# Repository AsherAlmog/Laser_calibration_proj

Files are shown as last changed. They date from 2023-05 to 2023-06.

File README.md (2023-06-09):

# Laser calibration
This repo contains code scripts to collect data of a laser beam's location using stepper motors that move the laser.<br>
The steppers are assumed to be controlled by an Arduino controller.<br>
We included some 3D models that we used to connect stepper motors to optical stages.<br>
This repo also contains a script for training a deep learning model to estimate the coordinates of the beam.<br>
# 3D models
For the ones who wish to build a similar setup by connecting 5mm stepper motors to ThorLabs' manual stages,
we included some useful 3D models under the folder *3D_models_STL_files*:<br>
The first is a coupler that connects the motor's shaft to the manual stage, named *coupler_13mm.stl*
and the second is *stepper_holder_z.stl* that is a stand for the motor.
# data collection process:
- **Arduino** - serial_comm_arduino.ino:<br>
This script is used to recieve a json file with a position to move to,
deserialize it and move 3 stepper motors accordingly.
- **Raspberry py** - data_collection.py:<br>
this script communicates with the arduino. it sends it a position to move to decoded in a json file,
and waits for an ack message. Then it captures a picture using the picamera and saves it in a directory
that is *hard coded* in the code. The next step is telling the arduino to nove back to the initial position.
there is a range of positions to iterate through that are also hard coded and should be changed manually if necessary.<br>
The following schematic shows the process:<br>
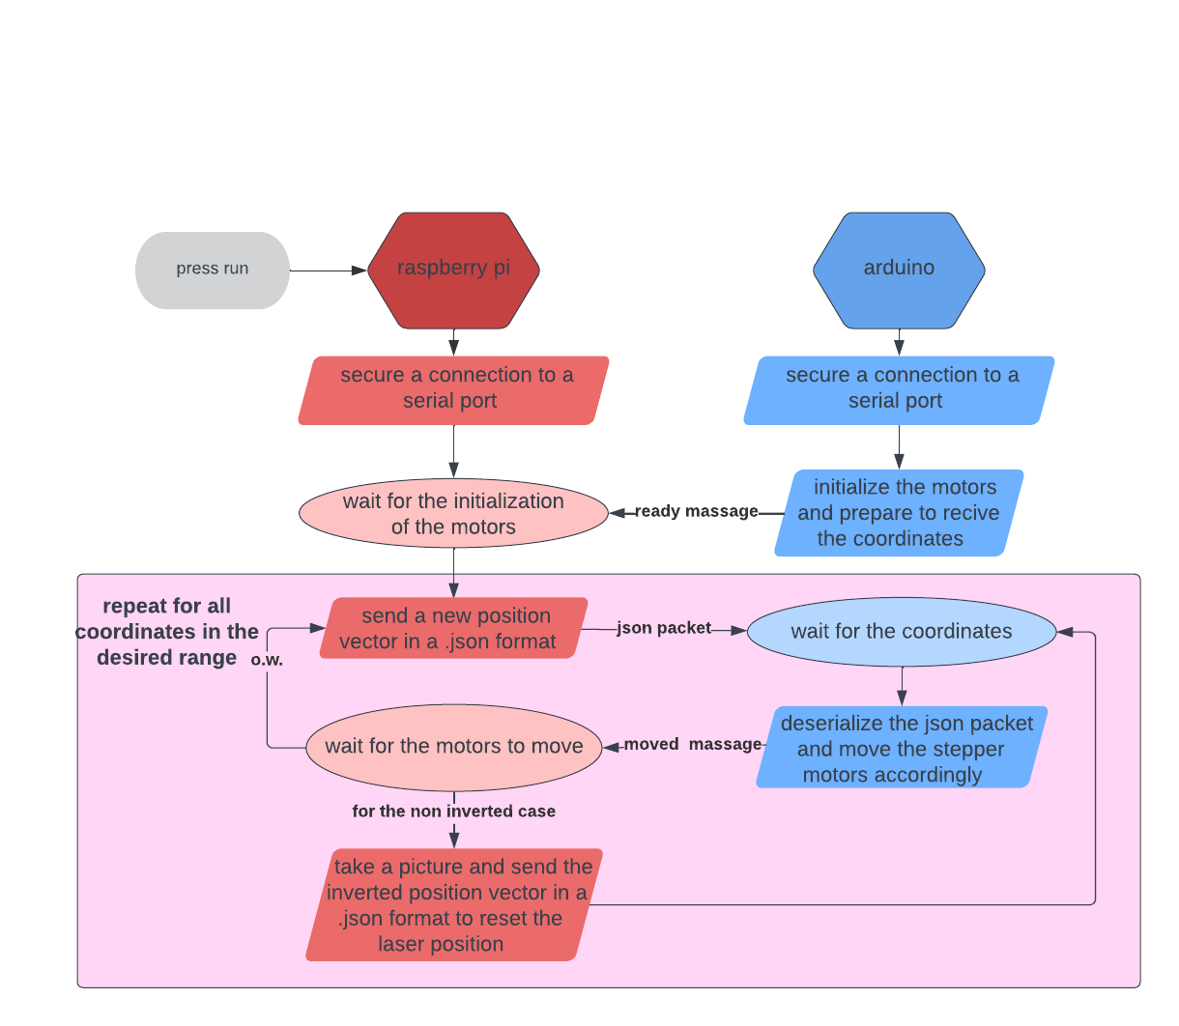
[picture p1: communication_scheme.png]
communication Image
 <br>
**In order to collect new data, follow the following steps:** <br>
1. Upload the *data_collection.ino* script to your Arduino <br>
2. In *data_collection.py*, change *root_dir* to the local directory in which you want to save the images. <br>
3. Still in *data_collection.py*, change the fields *bottom_bound*, *upper_bound* and *range_arr*. They're all organized in this order: [x,z,theta].
bottom_bound should be the lowest number of motor spins for each coordinate, upper_bound is the highest and range_arr determines the 
difference between each consecutive locations.<br>
4. Modify *num_iterations* to the number of images you wish to take for each coordinate.<br>
5. Run *data_collection.py* on your Raspberry-pi with the correct [camera module with the Sony IMX477 sensor](https://www.adafruit.com/product/4561).  <br>
# Deep learning model
original images: (1280, 960,3) images<br>
data transforms: turning the images to tensors<br>
The selected model: a pre-trained resNet-18 , with a modified FC layer<br>
Loss function : MSE<br>
optimizer: Adam<br>
Learning rate: starts at 0.01 and decreases by 70% every 8 epochs <br>
**In order to train a model:** <br>
Please change the *data_dir* variable in *train/main.py* to be the local directory that you saved the images in. <br>
Now run the script and you'll have a file named *model_params.pth* that contains the trained model's parameters.<br>
# Results
The MSE loss decreases significantly (starts at ~3, ends at ~0.05). <br>
Test loss is as below: <br>
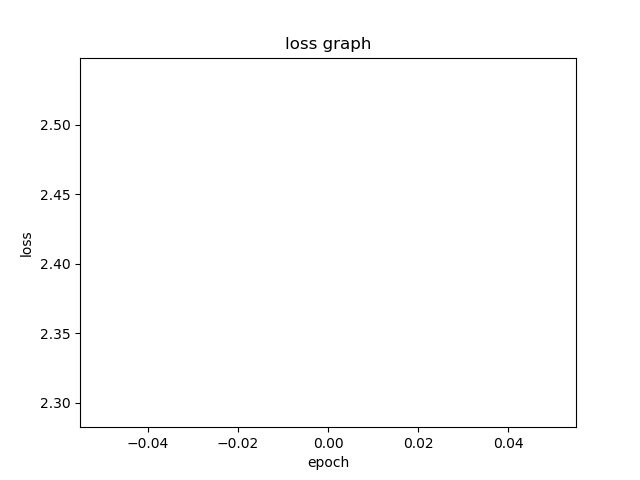
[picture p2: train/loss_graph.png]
test loss Image


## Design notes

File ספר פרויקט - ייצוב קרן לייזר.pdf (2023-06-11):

בי"ס להנדסת חשמל

## פרויקט מס' 22-1-1-2456

# ספר פרויקט

## שם הפרויקט: פרויקט ייצוב קרן לייזר

## מבצעים:

## שם: אלמוג אשר, ת"ז: 322417916

## שם: בר זהבי, ת"ז: 323014894

## מנחה: חן כהן

### מנחה נוסף: עופר כפיר

## מיקום ביצוע הפרויקט: מעבדת לייזרים בבניין

ברודקום )המעבדה של עופר כפיר(

## תקציר עבודה

כדי לייצב קרן לייזר נדרש לדעת את המיקום שלה בנקודת ייחוס, וכן את הזווית בה היא מתקדמת. אלו הן 4 דרגות חופש, שתיים בציר האופקי ושתיים באנכי.

השיטה כיום לאפיין את פרמטרים אלו של קרן לייזר, וכך גם לייצב אותה ע"י מראה ממונעת, היא שימוש בעדשות ומצלמות: מצלמה אחת מצלמת את הקרן כדי לקבוע את מיקומה. המצלמה הנוספת מקליטה את הפוקוס של הקרן לאחר עדשה, אשר נושא מידע על הזווית.

בפרוייקט זה ניתן היה להשתמש בתווך מפזר, דוגמת נייר לבן, חלון שירותים, ספוג או קיר, במקום עדשות. מכיוון שהפיזור יהיה תלוי במיקום הקרן וכן בזוויתה, שילובו עם מצלמה בודדת יאפשר את אפיון שני הפרמטרים האלו של הקרן על מצלמה יחידה, לאחר כיול או אימון המערכת.

הפיזור המתקבל מהקרן נקלט ע"י מצלמה של MP12 עם סנסור מסוג 477Imx Sony שמחוברת לבקר .Raspberry-pi

הבסיס התיאורטי לפרויקט הוא שיטה שעדיין לא מיצו את כל הפוטנציאל שלה והיא שימוש בתמונות הפיזורים של לייזר (images-speckle (על מנת ללמוד מאפיינים הן על הקרן והן על התווך המפזר.

- למשל בניטור תהליך התכה של מתכות בהם

i
השימוש בתמונות פיזורים כיום נעשה בעיקר בתהליכי ניטור רוצים לאפיין תכונות גיאומטריות של המתכת והרכב המתכת. או למשל בתהליכים ביו טכנולוגיים בהם יש לנטר את הביו- מסה של האורגניזם.

אנחנו מנסים לנצל את המידע הטמון בפיזורים למטרות אחרות – שיערוך של מיקום הקרן.

תמונות הפיזורים שמתקבלות על המצלמה שלנו משמשות כקלט לרשת למידה עמוקה מסוג 18Net-Res, שמוציאה כפלט את החיזוי של הזוויות והמיקום המרחבי שממנו נורתה הקרן. החיזוי משמש אותנו למעגל משוב, שמסתמך על פלט הרשת על מנת להחזיר את קרן הלייזר לראשית הצירים.

הן הזווית והן המיקום המרחבי נשלטים ע"י מנועי צעד שמחוברים לבקר מסוג Arduino, שמאפשרים לנו איסוף נוח של תמונות ומעגל משוב אוטומטי שמחזיר את הקרן לראשית. בפרויקט הוכחנו שאכן ניתן לכייל את הקרן באמצעות תמונו ת הפיזורים, לאחר שאימון על מאות קואורדינטות שונות עם אלפי דוגמאות קלט הביא את המודל לשגיאה ריבועית ממוצעת שמת קרבת לאפס הן עבור קבוצת האימון והן עבור קבוצת טסט.

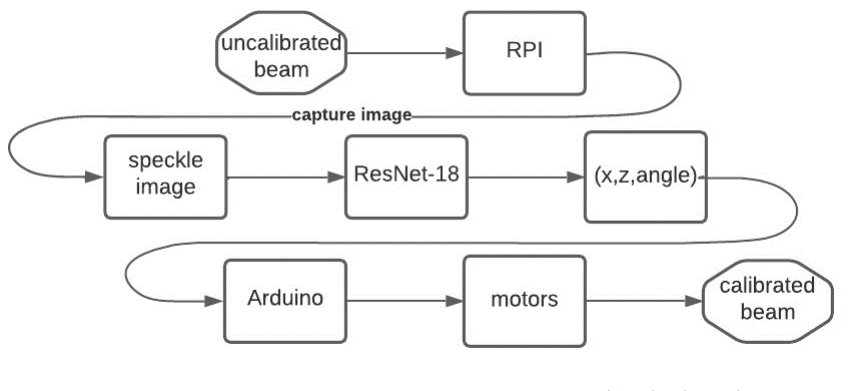
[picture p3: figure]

איור 1 - דיאגרמת בלוקים של תהליך הקליברציה

תוכן עניינים
תקציר עבודה 2 |
הקדמה 4 |
רקע תיאורטי 5 |
מימוש 6 |
המערכת הפיזית6 | :
אוטומציה והתממשקות למנועים: | 6
רכיבי המערכת הפיזית | 7
מימוש בתוכנה 13 |
תקשורת בין בקר ה-pi Raspberry לבקר ה-Arduino | 13
רשת למידה עמוקה | : 14
תוצאות 17 |
מסקנות 18 |
תיעוד 20 |
ביבליוגרפיה20 |

טבלת איורים

איור 1 - דיאגרמת בלוקים של תהליך הקליברציה | 2
איור 2 - המערכת הפיזית במהלך צילום תמונת פיזורים | 6
איור 3 - תמונה של בקר הראסברי-פאי 4 | 7
איור 4 - חיבורי המצלמה לפיני ה-GPIO של הבקר | 7
איור 5 - תמונה של בקר הארדואינו-מגה | 8
איור 6 - תמונה של ה1.4- RAMPS | 9
איור 7 - החיבורים הנחוצים בין הארדואינו ל -RAMPS וממנו למנועי הצעד | 9
איור 8 - סכמה של1.4 RAMPS | 10
איור 9 - חיבורי ה-PCB של ה-RAMPS | 10
איור 10 - הדרייבר שמניע את מנועי הצעד בקונפיגורציית חיבור בסיסית למנוע | 11
איור 11 - סכמה של מעגל Bridge-H | 12
איור 12 - קונפיגוריות של Bridge-H עבור סיבובים שמאלה וימינה | 12
איור 13 התקשורת בין הראסברי-פאי לארדואינו בעת איסוף הדאטה | 14
איור 14 - דיאגרמת בלוקים של השכבות ב-18-ResNet | 14

איור 15 - גרף השגיאה הריבועית הממוצעת בעת אימון המודל עבור קבוצת האימון וקבוצת הטסט .... 17

## הקדמה

פרויקט זה עוסק בכיול של קרן לייזר. מטרת העל של הפרויקט שלנו היא להצליח לבצע כיול של קרן לייזר אך ורק על סמך תמונות פיזורים של הקרן, שהן תמונות של הקרן שמתקבלות לאחר מעבר שלה דרך תווך מפזר שאינו שקוף. כיום תמונות פיזורים משמשות בעיקר לחיתוך וריתוך של מתכות ועוד לא מנוצלות לצרכים של שערוך מיקום, והפרויקט שלנו בא לבחון האם ניתן לנצל את המידע שטמון בתוך תמונות הפיזורים של הלייזר גם לצורך שיערוך המיקום של הקרן. את המשימה הכללית הזו ניתן לפרק למספר תתי משימות שהיה עלינו לבצע:
- ראשית, היה עלינו להקים מערכת אופטית שבבסיסה תכלול לייזר ותווך מפזר, ותאפשר שליטה גם במיקומו המרחבי של הלייזר וגם בזווית הפגיעה.
- המשימה השנייה היא להפוך את המערכת הפיזית ממערכת ידנית למערכת אוטומטית בצורה פשוטה וזולה – מאחר והמטרה בפרויקט היא גם לפשט באופן פרקטי את הכיול הן מבחינת נוחות למשתמש והן מבחינת עלויות הכיול, בנינו בתור התחלה מערכ ת שניתנת לשליטה ידנית ולכן חלקיה זולים, ולא עשינו שימוש בבמות ממונעות שמחירן יכול להגיע לעשרות אלפי שקלים. לאוטומציה של המערכת יש תפקיד חשוב בפרויקט שלנו – מערכת אוטומטית יכולה לאסוף דאטה בקלות מבלי שיהיה אפילו צורך לקחת חלק באופן פיזי באיסוף הדאטה, ומערכת אוטומטית גם יכולה לבצע את הכיול של הלייזר באופן עצמאי לאחר אימון חד פעמי של רשת קונבולוציה.
- המשימה השלישית הייתה לתכנן רשת למידה עמוקה שתתאים לבעיה שלנו הן מבחינת הגודל והן מבחינת זמן הריצה העתידי שלה.
- לבסוף, עלינו להשתמש במודל המאומן כדי ליצור מערכת שתוכל לכייל את עצמה באופן אוטומטי.

הסיבה שבגללה בחרנו להשקיע את מאמצינו בלכייל קרן לייזר היא בגלל השימושים ההולכים וגוברים בלייזרים בימינו בישומים שדורשים דיוק גבוה – עבודה עם סיליקון וחיתוך של חומרים כמו מתכות ופלסטיקים, שבהם נדרש דיוק גבוה. מכשור רפואי שדורש דיוק גבוה, כמו למשל בניתוחים בעין שמצריכים לייזר והדיק של הלייזר בהם הוא קריטי.
מחקרים ביולוגיים, כמו למשל מחקרים של ה DNA שמצריכים עבודה עם לייזר וגם הם כמובן מצריכים רזולוציות גבוהות.
כל אלו מצריכים מאיתנו להגיע לרזולוציות גבוהות מאוד בכיול לייזר והופכים את הפוטניצאל האפליקטיבי של שיטת כיול נוחה ומהירה לגדול מאוד.

בפרויקט שלנו רצינו לנצל תכונה מיוחדת של הלייזר – והיא יצירת תבניות פיזורים לאחר מעבר דרך תווך מפזר, ושכל שינוי באחת מדרגות החופש של הקרן יוצר תבנית פיזורים חדשה. השינוי הזה בתבניות הפיזורים הביא אותנו להאמין שבשילוב עם רשתות למידה עמוקה וזיהוי והתאמת התבניות לקואורדינטות המתאימות, ניתן יהיה לכייל את קרן הלייזר ברזולוציות מאוד גבוהות בהסתמך אך ורק על תמונות הפיזורים שלה. כיול באופן כזה הוא מאוד פשוט, שכן בשילוב עם אוטומציה של המערכת קל מאוד לתת למערכת לאסוף דאטה לבד ולאמן בעצמה מודל מבלי אפילו להיות צריכים להיות נוכחים פיזית, וכל זאת עם מצלמה אחת בלבד שתצלם את הקרן לאחר פגיעה בתווך המפזר. זאת לעומת השיטות הקיימות כיום שמחייבות שימוש בשתי מצלמות – אחת למיקום ואחת לזווית.

בכך אנחנו מצמצמים הן את עלות הסטאפ והן את כמות המידע שצריך לעבד )פי 2 פחות מידע כי מספר הפיקסלים קטן בחצי(. הרחבה על היתרונות התיאורטיים לעומת השיטות הקיימות תיעשה בתת הסעיף הבא.

## רקע תיאורטי

הפרויקט שלנו בראש ובראשונה מתעסק בלייזר – או ב שמו המלא,לצורך
מונוכרומטי | אור | שפולא | מכשיר | הוא ,Light Amplification by Stimulated Emission of Radiation
וקוהרנטי. מונוכרמטי משמעותו ש הלייזר פולט גלים בעלי אורך גל זהה )שאצלנו נמצאים בתחום הצבע האדום(, וקוהרנטי משמעותו שאין הפרשי פאזה בין הגלים הנפלטים.
– כלומר תמונות של הקרן כפי שהן מתקבלות | ii | בפרויקט שלנו התמקדנו בתמונות פיזורים של הלייזר
לאחר מעבר דרך תווך מפזר כגון נייר, צבע לבן או כל תווך שאינו שקוף וגורם לפיזור של הלייזר. מתקבלות תמונות של מה שנראה כמו חלקיקים של הלייזר, במה שנוצר בגלל התאבכות של גלים שהיו פעם חלק מחבילת הגלים הפוגעת של קרן הלייזר וחזרו עם פאזות שונות. תיאור פשטני של גל המתפשט
(ω−k) | במרחב בכיוון x למשל יהיה A
והפאזה שלו תהיה ω − k + ()arg , כש- היא התדירות

ו-k הוא מספר הגל שפרופורציונלי להופכי של אורך הגל. ניתן למצוא אותו ע"י =

2π
λ

הייחודיות של תמונות הפיזורים היא בכך שכל שינוי קטן במיקום וזווית הפגיעה מובילים לשינוי בתמונת הפיזורים המתקבלת. זאת מאחר וכל נקודה בתווך המפזר תיתן לנו תבנית התאבכות שונה, בטח אם התווך הוא לא אחיד.
המטרה שלנו בפרויקט היא לנצל את התכונה הזו של תמונות הפיזורים כדי להצליח לכייל קרן לייזר ברזולוציות גבוהות אך ורק ע"י תמונת הפיזורים שלה. הנחת הבסיס היא שמאחר ותבנית הפיזורים תהיה שונה לכל נקודה, איסוף של כמות גדולה של תמונות פיזורים )הכמות כמובן תלויה ברזולוציה אליה רוצים להגיע(, תוכל לאפשר שיערוך של מיקום הקרן מתוך התמונה תוך שימוש במודל למידה עמוקה, ומתוך כך גם כיול של הקרן על סמך השיערוך.
, פעם | iii | כיום השיטות לכיול הקרן אינן מסתמכות על תמונות הפיזורים שלה, אם כי על צילום הקרן עצמה
אחת ישירות כדי למדוד את מיקום , שלה ופעם אחת לאחר פיזור מעדשה וצילום הקרן עם מצלמה נוספת לאחר הפגיעה בעדשה. באמצעות מיקום הפגיעה לאחר העדשה וידיעת התכונות של העדשה המפזרת ניתן לחשב מה הייתה זווית הפגיעה. שיטה נוספת שכרגע עדיין בגדר מחקר בלבד הינה צילום הקרן במספר נקודות שונות וביצוע אינטרפולציה
iv | לשיערוך המיקום של הקרן
לשיטה שאנחנו יש יתרון משמעותי על פני השיטות האלה – אנחנו צריכים רק מצלמה אחת במקום שתיים. אנחנו מציעים סביבה זולה מאוד לצורך כיול הקרן – מצלמה אחת בלבד, שני בקרים פשוטים ומספר מנועי הצעד כמספר דרגות החופש שבהן רוצים להתחשב. מעבר לעלות, החשביבות במצלמה אחת באה לידי ביטוי גם בזמן הריצה – יש פי 2 פחות מידע לעבד ולכן ניתן להשיג זמן ריצה משמעותית יותר טוב. אנחנו גם מתבססים על שיטה פשוטה בהרבה שלמעשה לא מצריכה מאמץ כמעט בכלל – במערכת אוטומטית כמו שלנו כל שצריך לעשות הוא לתת לרשת לצלם תמונות ולאמן מודל בעצמה, ולהגיע יום למחרת כשכבר ישנה רשת קונבולוציה מאומנת שיודעת לשערך את מיקום הלייזר מתוך תמונות הפיזורים.

## מימוש

המערכת הפיזית:

הרכיב העיקרי במערכת הוא כמובן הלייזר, לייזר אדום מדרגה 3B. הלייזר יושב על במה שממנה יוצאת לשונית מסתובבת שמאפשרת לשנות את גובהו של הלייזר. במערכת קיימות גם שתי מראות שמטרתן לאפשר לנו לשלוט גם בזוויות הפגיעה וכן במיקום על ציר X. גם בהן השליטה מתאפשרת באמצעות לשוניות שבולטות מהבמה וניתן לסובב אותן כדי לשנות את המיקום. לבסוף ישנו תווך מפזר, במקרה שלנו ניילון שאינו לגמרי שקוף, שלאחריו מוצבת מצלמה המחוברת לבקר ראסברי-פאי ויכולה לצלם את תמונות הפיזורים.

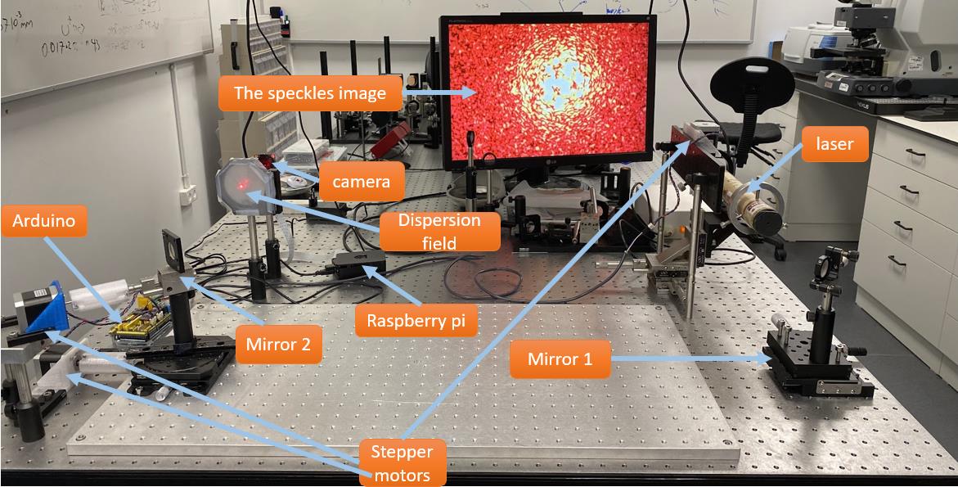
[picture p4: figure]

איור 2 - המערכת הפיזית במהלך צילום תמונת פיזורים

### אוטומציה והתממשקות למנועים:

כפי שניתן לראות באיור של המערכת, כל אחת מהלשוניות ששולטות בקואורדינטות ממומשקת למנועי צעד. כך ניתן לשלוט בקלות במיקום המערכת ולהשיג שתי מטרות חשובות -הראשונה שבהן היא איסוף מהיר ואוטומטי של תמונות לאימון מודל למידה עמוקה, והשנייה היא להיות מסוגלים לבצע פידבק על סמך השיערוך של המודל ולכייל את הלייזר בצורה אוטומטית ולא ידנית. ההתממשקות למנועי הצעד נע שתה באופן הבא: על מנת לחבר את הזרוע של מנועי הצעד ללשוניות של הבמות, תכננו באמצעות תוכנת 360 Fusion מודל תלת מימד של מצמד גמיש. המצמד שמידלנו בנוי כך שמצד אחד יש חור בקוטר של הזרוע של מנוע הצעד, בעוד שמהצד השני יהיה חור בקוטר של הלשונית. היתרון העיקרי של המצמד שלנו הוא ש לאורך הגליל השארנו מרווח כך שנוכל להדק את המצמד על הזרוע של המנוע ועל הלשונית באמצעות בורג ואום 3M וכך להבטיח חיבור חזק של הזרוע ללשונית והשפעה מינימלית של החיכוך. המדידות של הקטרים נעשו בצורה מדויקת ע"י קליבר אלקטרוני. בנוסף לכל אחד מהמנועים הדפסנו סטנד שעליו הוא יושב עם חורים במיקומים המתאימים מסביב לזרוע כך שנוכל לקבע את המנוע בתוך הסטנד. הסטנד מאפשר לנו להפחית את החיכוך עם השולחן האופטי, ומאפשר לנו להניע את המנועים בתוך מסילה מוגדרת שבנינו ובכך למנוע מהם תזוזות שיצרו הפרעות וסטיות במערכת.
השליטה במנועים נעשתה באמצעות בקר Mega Arduino עם shield מסוג 1.4 RAMPS, ועל כך נרחיב בתת הכותרת הבאה )רכיבי המערכת(.

## רכיבי המערכת הפיזית

ראשית נתחיל מתיאור קצר של הבקרים, יכולותיהם, האופי בו הם מתממשקים ושימושם בפרויקט זה: Raspberry-Pi

:

v
תמונה של הבקר עליו נרחיב כעת

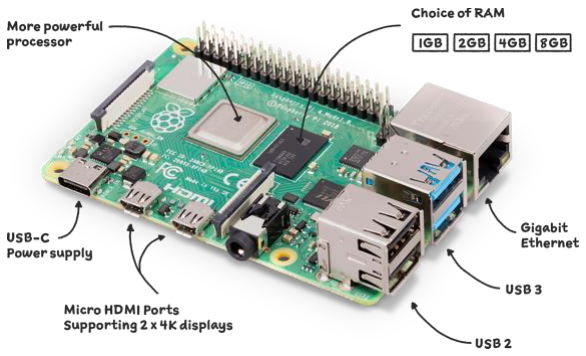
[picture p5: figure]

איור 3 - תמונה של בקר הראסברי-פאי 4

בקר זה הינו computer board single שפותח על ידי חברת Broadcom באנגליה, בפרויקט שלנו אנו משתמשים בסדרה 4 של בקר זה בכדי לנצל את השדרוג ביכולות העיבוד שלו מול הגרסה הקודמת והפופולארית שלו 3 RPI, הRPI נוצר בכדי להיות כלי המאפשר ללמד על כל תחומי ההנדסה בדגש על תכנות ורובוטיקה.
בחרנו בו מכיוון שהייתה לו יכולת להתממשק עם חיישן 477Imx Sony( בעזרת תושבת הנמכרת עם החיישן( בו אנו משתמשים לצילום הלייזר ועליו נפרט בהמשך, בנוסף ישנה התממשקות עם חיבורי USB ועם חיבור HDMI-micro, והדבר שהכי היה חשוב לנו הייתה האפשרות להריץ סקריפטים של פייתון ועריכה שלהם בעזרת ה-IDE המותקן עליו. חיבורי ה-connector camera CSI בהם נעשה שימוש הנמצאים על הבקר הם כמו שניתן לראות בתמונה :

הבאה vi

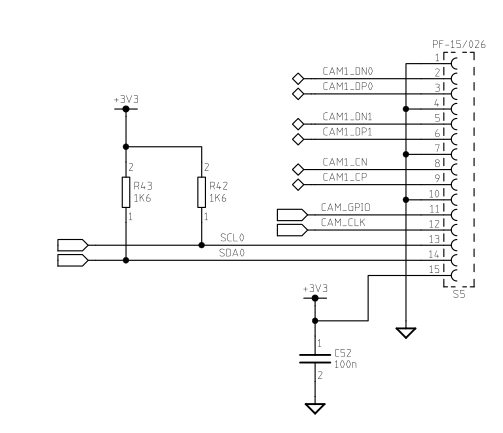
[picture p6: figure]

איור 4 - חיבורי המצלמה לפיני ה-GPIO של הבקר
שימוש ב4- RPI איפשר דרך התממשקות מה -script שנכתב בשפת python למצלמה מחד ולבקר של המערכת המכנית ( ה-Arduino (מאידך, לכן הבחירה בו הייתה זו המתאימה ביותר לצרכינו בפרויקט זה, בהמשך נפרט עוד על המצלמה בחלק זה ועל אופן התקשורת בחלק המימוש התוכנתי, עוד על אופי העבודה .

של בקר ה -RPI ניתן לפרש מהסכמות המופיעות ב אתר הרשמי של ה-developers שלו vii

Arduino mega 2560

:

תמונה של הבקר עליו נפרט בהמשך viii

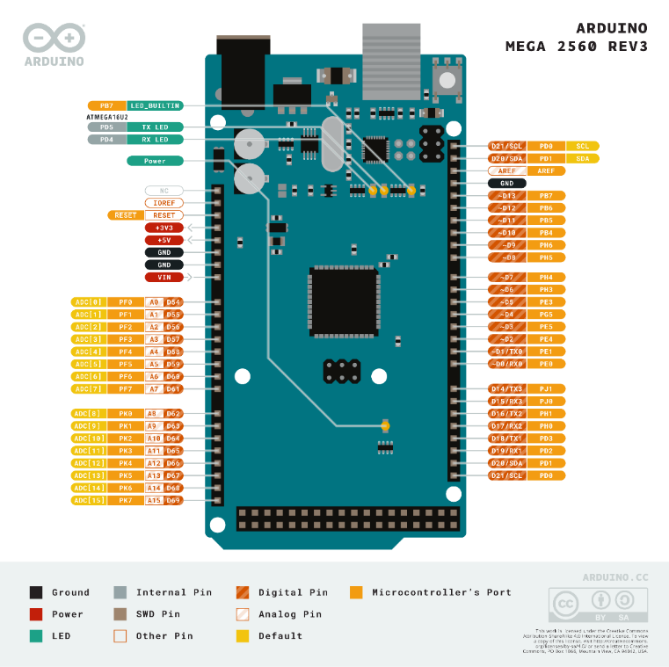
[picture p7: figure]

איור 5 - תמונה של בקר הארדואינו- מגה
בחירה בבקר זה הייתה שילוב של צורך בשליטה במנועים אשר להנעתם צריך להשתמש בזרם גבוהה, והעובדה ששליטה זו צריכה להתאפשר באופי תוכנתי )כדי שכל חלקי המערכת יעבדו באופן שלא מצריך עירוב של המשתמש(, בפרק של התקשורת של הבקרים יוסבר על אופן התקשורת בה השתמשנו בכדי לעבור מהרצה של תוכנית ב-python לסיבוב הפיזי של המנועים, כל זה מתאפשר רק בזכות השילוב של הסיפריות המוצעות כחלק מה -IDE של בקר זה בשילוב עם ה-ports הפיזיים בהם הוא מצוייד, עוד דבר שהוביל לבחירה זו היה החיבור שלו עם ה1.4- RAMPS אשר איפשר ממשק בין פיני ה-O\I של הבקר ל-Drivers של מנועי הצעד.
בקר זה מאפשר שליטה תוכנתית בכל ה-pins O/I שלו, בנוסף גם ישנה אפשרות להעברת מידע סריאלית מפורט ה -USB שלו, שהיא עוד אחת מהסיבות שבחרנו דווקא בו.

RAMPS 1.4

ה-shield עליו נפרט כעת )עם כמה drivers שונים, נשתמש ב-driver הסגול ה 8825-DRV לאפליקציה שלנו
: ix | עליו נפרט בהמשך( נראה כך

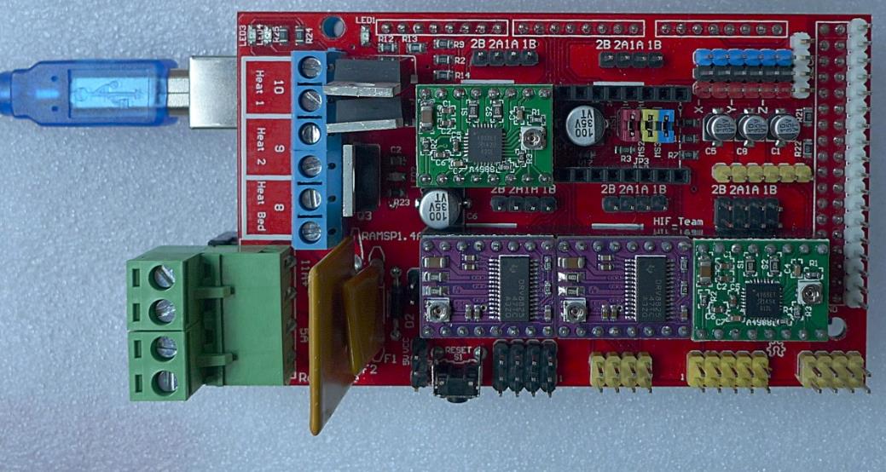
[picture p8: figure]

איור 6 - תמונה של ה1.4- RAMPS
)RAMPS - RepRap Arduino Mega Pololu Shield( Arduino- ה | לבקר | המיוצרים | shields- מה | אחד | זהו
הוא משמש בד"כ לייצור מדפסות תלת מימד בייתיות, אך במקרה שלנו השתמשנו בו בצורה קצת שונה בשל יכולת השליטה שלו ב5- מנועים שונים )בד"כ מחברים 2 מנועים לציר z )אופן החיבור השכיח שלו
:x | באפליקציית הדפסת התלת מימד נראה כך

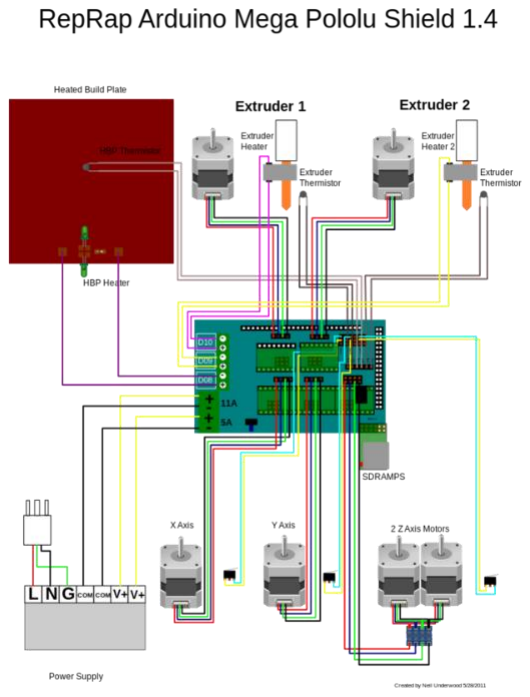
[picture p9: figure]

איור 7 - החיבורים הנחוצים בין הארדואינו ל-RAMPS וממנו למנועי הצעד

הסכמה שלו נראית כך:

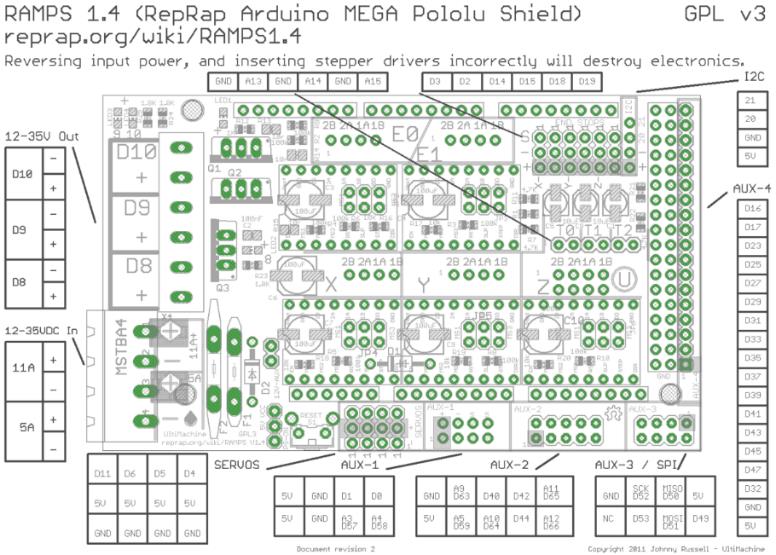
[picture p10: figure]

איור 8 - סכמה של1.4 RAMPS
והוא מציג את אופן התממשקות ה -shield עם בקר ה-mega Arduino עם החיבורים הפנימיים שלו באופן הבא:

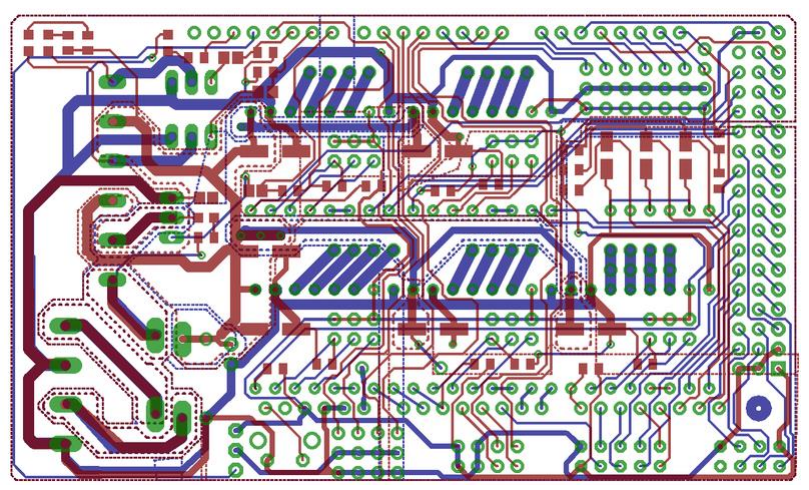
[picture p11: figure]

איור 9 - חיבורי ה-PCB של ה-RAMPS

:DRV8825

:

תמונה של הדרייברxi

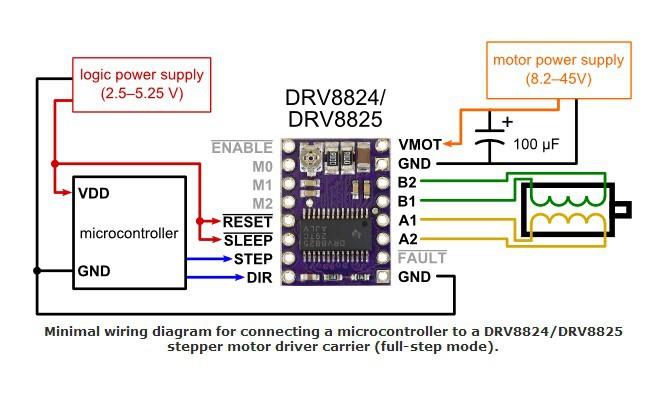
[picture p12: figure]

איור 10 - הדרייבר שמניע את מנועי הצעד בקונפיגורציית חיבור בסיסית למנוע
רכיב זה נמצא על ה 1.4- RAMPS שלנו ומהווה את הקשר בין כל ה -motors stepper שלנו לפינים המצוינים בתוכנה, ניתן לראות מן התמונה כי אנו מקבלים 2 סיגנלים בכניסת הדרייבר, הראשונה הינה כניסת ה-step אשר במקרה שלנו מציינת את כמות ה -microsteps שהדרייבר צריך לבצע והשנייה הינה DIR שהיא בעצם סיגנל בינארי המציין אם המנוע שלנו צריך להסתובב בכיוון (CW (clockwise או .counter-clockwise (CCW)
ברכיב זה השתמשנו בכדי להגיע לדיוק גבוהה יותר ובכדי לחסוך צורך בבניית bridge-H חיצוני בכדי לשלוט במנועים )נרחיב על bridge-H בהמשך(.

עבור כניסת ה-step הדרייבר הספציפי שלנו ניתן להגיע לרזולוציה של

1
32

כלומר כל 32 microsteps המנוע

שלנו יבצע step יחיד )דבר המאפשר להגיע לרזולוציות גבוהות מאוד בסיבוב הפיזי של הלשונית של הבמות האופטיות(, השתמשנו בבקר זה בכדי להגיע לאחוז דיוק גבוהה מאוד בין הסיבובים, כלומר שכמות סיבובים זהה עבור DIR שונה תחזיר את המערכת למיקום הקודם שלה בדיוק המיטבי. עבור כניסת ה -DIR ניתן לראות בשרטוט כי ה-motor stepper שלנו מחובר בקונפיגורציה של ארבעה חוטים )כי הוא בי-פולארי(, הם מחולקים לקבוצות של 2 הנותנות לנו את האפשרות להסתובב בשני הכיוונים )CW וCCW), בסופו של דבר הדרייבר מחלק אותם כך שעבור כל אפשרות של DIR נקבל קבוצה שונה ובכך נקבל את השליטה המלאה על כל הטווחים שנרצה )תרגום של CW וCCW יכול להיות לעלייה/ירידה של אחד מן הצירים בעזרת החיבור ללשוניות(. דרייבר זה משתמש בצ'יפ 8825DRV של Instruments-Texas אשר מצויד ב2 drivers bridge-H ובנוסף יש לו indexer microstepping העוזר להגעה לרזולוציות המדוברות.

:H-bridge
תמונה של המעגל שנלקחה מ xii-Wikipedia:

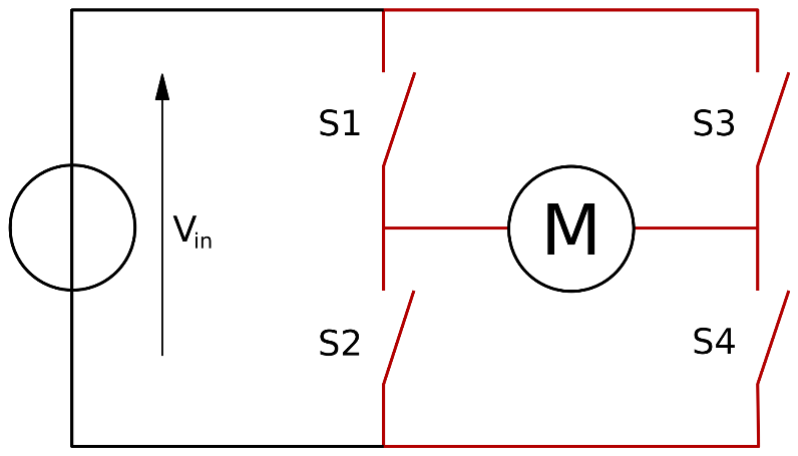
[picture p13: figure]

איור 11 - סכמה של מעגל Bridge-H
מעגל ה-bridge-H עובד באופן הבא המיוצג בטבלה הבאה:
S4 | S3 | S2 | S1 | mode
1 | 0 | 0 | 1 | Motor moves right
0 | 1 | 1 | 0 | Motor moves left
0 | 0 | 0 | 0 | Motor coasts
0 | 0 | 0 | 1
0 | 0 | 1 | 0
0 | 1 | 0 | 0
1 | 0 | 0 | 0
1 | 1 | 0 | 0 | Short circuit
0 | 0 | 1 | 1
0 | 1 | 0 | 1 | Brakes
1 | 0 | 1 | 0

כלומר ניתן לראות כי את כל הפונקציונאליות שלו ניתן להשיג משלושת המצבים )right moves Motor left moves Motor וBrakes ) מהם המצבים של סיבוב שמאלה וימינה מצוינים בתמונה הבאה:

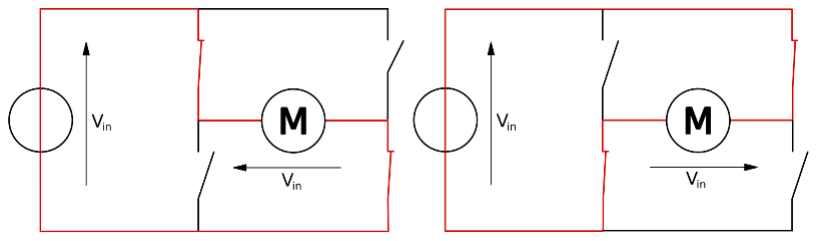
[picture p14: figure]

איור 12 - קונפיגוריות של Bridge-H עבור סיבובים שמאלה וימינה
מעגל זה משמש בד"כ לאספקת מתח למעגלים בי-פולאריים ועובד על העיקרון בו ניתן לסגור מעגל באיזה אחת מהדרכים שנרצה )ב2 תצורות הזרם האפשריות ב-DC במנוע( ובעזרת סיגנל דיגיטלי לשלוט בו. מימוש פיזי של רכיב כזה הינו NE754410SN של TIxiii.

### מימוש בתוכנה

### תקשורת בין בקר ה-pi Raspberry לבקר ה-Arduino

על מנת לאסוף את הדאטה שלנו באופן אוטונומי, מהיר ויעיל, מימשנו ערוץ תקשורת בין בקר הארדואינו ששולט במנועי צעד לבין בקר ה-RPI ששולט במצלמה שמצלמת את תמונות הפיזורים. התקשורת בין שני הבקרים הינה תקשורת סיריאלית – כלומר על מנת להעביר הודעות מאחד לשני עליהם להיות מחוברים בכבל.
פיני ה-GPIO) Output/Input Purpose General (של ה-pi Raspberry מחוברים לפינים הסיריאלים שיש לארדואינו, והתקשורת נעשית בפרוטוקול UART שבו הדאטה עוברת מבקר אחד לשני בצורה של ביט-ביט.
עלינו לקבוע rate baud זהה עליו יתקשרו שני הבקרים, כשה -rate baud מייצג את כמות הביטים לשניה שעוברים בערוץ התקשורת. אנחנו בחרנו rate baud של 9600 ביטים לשניה. מימוש התקשורת שעשינו מתבסס על עיקרון מאוד בסיסי בתקשורת שהוא messages ack )ack כקיצור ל- acknowledgement). ראשית הראסברי-פאי מחכה להודעת ack ראשונה וחד פעמית מהארדואינו שמציינת שהוא סיים את שלב ה-setup ומוכן לשמוע ולשלוח הודעות. לאחר מכן מבצעים עבור כל קואורדינטה שעבורה רוצים לאסוף תמונת פיזורים את התהליך הבא: ראשית, הראסברי-פאי מקודד לקובץ json. את הקואורדינטה שבה רוצים לצלם. הוא מקודד לכל אחד מהמנועים כמה סיבובים עליו לבצע ובאיזה כיוון. הארדואינו קולט את את ההודעה ומבצע דיסר יאליזציה של קובץ ה-json ובכך מפענח כמה סיבובים כל מנוע צריך לבצע ובאיזה כיוון. לאחר הזזת המנועים הארדואינו ישלח message ack אל הראסברי-פאי שמשמעותה שהוא סיים להזיז את המנועים למקום המבוקש והראסברי יכול לצלם תמונה. הראסברי מצלם תמונה, שומר אותה בכונן חיצוני שמיקומו הלוקאלי מוגדר ע"י המשתמש בקוד, ולאחר מכן שולח הודעה לארדואינו שהוא יכול להחזיר את המנועים למיקומם המקורי, והארדואינו שוב ישלח message ack שהוא סיים להחזיר את המנועים.
תהליך זה חוזר עבור כל נקודה שנרצה לצלם ויחזור על סט הנקודות שנבחר לכמות מסוימת של איטרציות המוגדרת בקוד )הדאטה שלנו נאספה כך שיש 30 תמונות שצולמו לכל קואורדינטה(.

הסכמה הבאה מציגה בצורה טובה את תהליך התקשורת בין הבקרים וצילום הדאטה:

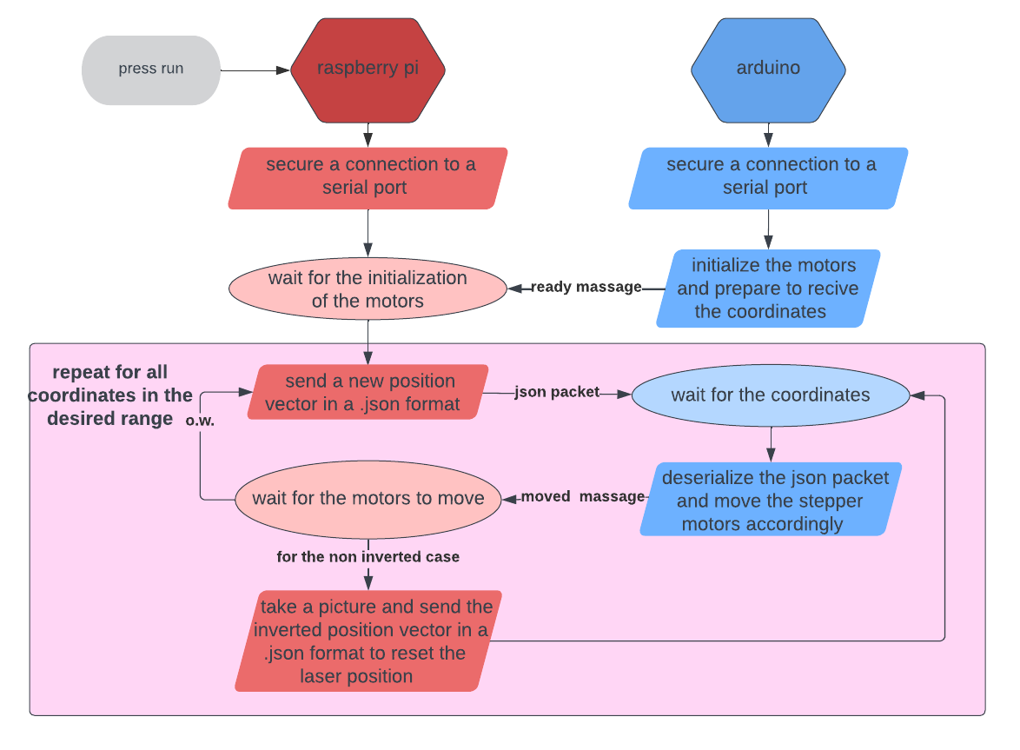
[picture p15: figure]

איור 13 התקשורת בין הראסברי-פאי לארדואינו בעת איסוף הדאטה

### רשת למידה עמוקה:

שיערוך המיקום שלנו למעשה מתבסס לחלוטין על מודל למידה עמוקה מסוג learning supervised. כלומר, אנחנו מכניסים למודל שלנו דוגמאות של תמונות פיזורים יחד עם הקואורדינטות המתאימות לכל תמונה, ובכך מלמדים את המודל להבחין בין הקואורדינטות השונות לפי השוני בין התמונות. זוהי גם הסיבה שלשמה היינו צריכים כמות גדולה של דאטה – עם כל היתרונות המהותיים של רשתות למידה עמוקה והתוצאות יוצאות הדופן שניתן להוציא מהן, החיסרון המשמעותי העיקרי שלהן הוא שהן מצריכות כמות גדולה של דוגמאות קלט כדי להצליח "ללמוד". בפרויקט שלנו בחרנו להשתמש בספריית pyTorch, שהיא ספריה מובנית ומוכרת בפייתון שמ אפשרת שימוש נוח ברשתות קונבולוציה ולמידה עמוקה. בחרנו להשתמש בארכיטקטורת 18Net-Res, שבנויה כלהלן:

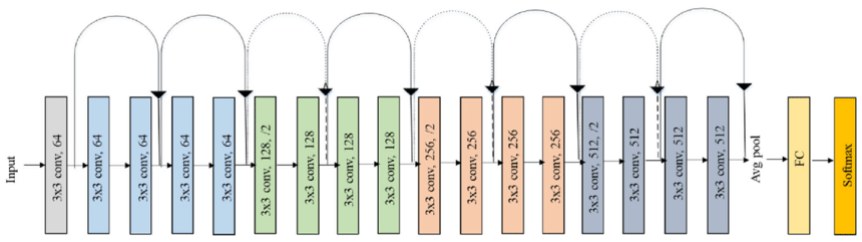
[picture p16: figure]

איור 14 - דיאגרמת בלוקים של השכבות ב-18-ResNet

ניתן לראות שהרשת מורכבת משרשרת ארוכה של שכבות קונבולוציה, שבסופן pool Avg שהיא למעשה להעביר מסנן מיצוע על הפלט של שכבות הקונבולוציה. לאחר מכן מגיע שיטוח של פלט ה- pooling ומעבר
.softmax | ולבסוף | fully-connected | בשכבת
הסיבה שבחרנו להשתמש דווקא בארכיטקטורה זו היא ראשית בגלל שהיינו צריכים ארכיטקטורה שבה תהיה כמות גדולה יחסית של פרמטרים שניתן "ללמד". תמונות הקלט שלנו הן יחסית גדולות - גודלן 3x690x1280 ובנוסף יש לנו אלפי תמונות קלט לעבוד איתן וכן מדובר בבעיית רגרסיה שמצריכה מאיתנו לשערך כמות גדולה מוד של קואורדינטות אפשריות. ועם זאת מדובר ברשת לא מאוד גדולה יחסית לארכיטקטורות נוספות כמו 50ResNet ולכן גם תגובת ה-

time Real שלה היא לא מאוד ארוכה, שזה חשוב לנו בהתחשב בעובדה שנרצה לבצע משוב בזמן אמת

ע"מ לכייל את הקרן בצורה אוטומטית. זמן התגובה של הרשת כשמריצים איתה חיזוי על pi Raspberry הוא כ- 0.1 שניות, כשברוב הרשתות הגדולות יותר זמן התגובה גדל פי כמה, שזה משמעותי כשמדברים בסדרי גודל של שניות.
הקלט לרשת שלנו היה התמונות המקוריות בלי שינויים כלשהם – בדיקה של תוצאת החיזוי עם טרנספורמציות שונות לתמונות הקלט העלתה ששימוש בתמונות בגודלן המקורי ובלי מניפולציות על ערכי הפיקסלים נותן את התוצאה הטובה ביותר.

כדי לעדכן את הפרמטרים ברשת, השתמשנו ב-optimizer Adam: זהו למעשה עדכון אדפטיבי של הפרמטרים במערכת שהוא בדרך כלל יעיל יותר מאלגוריתמים ישנים כמו SGD למשל.
:

הרקע המתמטי לאלגוריתם xiv

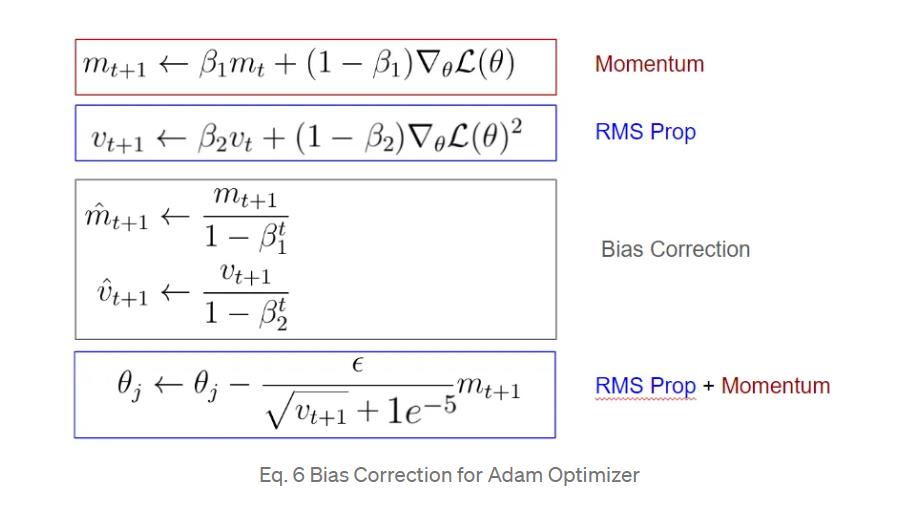
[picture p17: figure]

mt הוא מומנטום אדפטיבי שמתעדכן בכל

כאשר θ מייצג את הפרמטרים שאותם אנו רוצים לעדכן,

vt הוא גורם RMS שגם הוא מתעדכן, ו2-β 1,β הם hyperparameters שאנחנו מאתחלים איטרציה,
אותם.

האדפטיביות שלו לעומת אלגוריתמים אחרים מאפשרת לו בדרך כלל להשיג תוצאות טובות יותר במיוחד במקרים כמו שלנו שבהם מאגר הדאטה הוא לא ענק, והוא הוכיח את עצמו גם עבור הדאטה שלנו כשנתן התכנסות מהירה יותר מאלגוריתמים אחרים. כקריטריון השתמשנו בשגיאה ריבועית ממוצעת – loss MSE . הבחירה נעשתה מתוך התחשבות בסוג הבעיה איתה אנו מתמודדים – אנחנו למעשה מנסים לשערך מיקום, שהוא משתנה רציף, גם אם כמות הקואורדינטות שא ספנו בדאטה שלנו היא על פניו מוגבלת ועברה דיסקרטיזציה. יש לה יתרון מוכח בבעיות של שיערוך מיקום, ומעבר לכך יש לה תכונה שרצינו ליישם במודל שלנו- ה"קנס" שלה הוא גדול יותר ככל שהשגיאה המרחבית )כלומר הסטייה של הקואורדינטות המשוערכות ביחס לקואורדינטות האמיתיות של אותה התמונה( גדולה יותר. ככה למעשה כשביצענו דיסקרטיזציה למיקום יכולנו "לקנוס" יותר על מקרים שבהם החיזוי של המודל חורג לקואורדינטה אחרת, ופחות על מקרים שבהם עיגול נכון של החיזוי יתן לנו את הקואורדינטה הנכונה.

את הדאטה שאספנו חילקנו באופן הבא – 80% מהתמונות שאספנו שימשו כדוגמאות לאימון, וה20%-הנותרות שימשו כדוגמאות מבחן – כלומר בכל פעם שביצענו איטרציה של אימון ועדכון פרמטרי המודל, בדקנו את הביצועים על קבוצת המבחן. בכך מנענו מהמודל להתאים את עצמו רק לדוגמאות האימון ולהיכשל במבחן על תמונות אחרות. החלוקה לאימון וטסט נעשתה באופן רנדומלי. בנוסף בחרנו להשתמש ב-size batch של 16 – כלומר כל עדכון של המשקולות נעשה רק לאחר עיבוד של 16 תמונות בכל פעם. בכך יכולנו לנצל יתרון של המשאבים שהיו בידינו – יכולנו לאמן במקביל על GPU 4 שונים ולקיחת size batch של 16 אפשרה לנו למקבל את תהליך האימון בין ארבעתם, מעבר לכך ש-size batch גדול יותר הוא באופן כללי כלי להאצת תהליך האימון.

קצב האימון ההתחלתי שבחרנו הינו 0.01 = rate learning שהוא אמנם נראה כגדול יחסית, אבל בשל ה-size batch היחסית גדול רצינו קצב למידה גדו ל לאיטרציות הראשונות. בכל 8 איטרציות קצב הלמידה קטן ב70%- .

## תוצאות

התוצאות שקיבלנו לאחר אימון המודל היו מעודדות למדי – ייצאנו גרף של השגיאה הממוצעת על דוגמאות האימון בכל איטרציה וכן של השגיאה על דוגמאות הטסט בכל איטרציה, וקיבלנו את הגרף הבא:

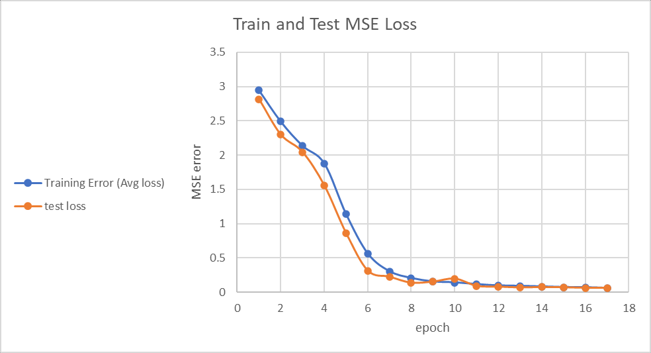
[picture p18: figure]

איור 15 - גרף השגיאה הריבועית הממוצעת בעת אימון המודל עבור קבוצת האימון וקבוצת הטסט
קל מאוד להבחין בכך שהשגיאה יורדת מהר מאוד לקרוב לאפס, במה שמצביע באופן ישיר על כך שהמודל מצליח לחזות בקירוב גבוה מאוד את הקואורדינטות עבור התמונות עליהן הוא מתאמן, וחשוב בהרבה – הוא מצליח לחזות נכון גם עבור דוגמאות הטסט. השגיאה הריבועית הממוצעת ירדה עד כדי פי 100 מהשגיאה ההתחלתית. לאחר אימון המודל, שמרנו את פרמטרי המודל המאומן )לאחר 30 איטרציות( בקובץ pth שניתן לטעון בקלות ולהשתמש בספריית pyTorch על מנת לבצע איתו חיזוי לתמונות חדשות.

התוצאות שלנו גם עונות על הדרישות שלנו בתחילת תוכנית העבודה – השאיפה הראשונית הייתה שתוך 5 איטרציות של חיזוי מיקום והזזה לפי החיזוי נצליח להביא את הקרן לראשית הצירים. בפועל החיזוי שלנו מדויק מה שציפינו להשיג וברוב הפעמים מצליח תוך פעם אחת בלבד לחזות את הקואורדינטות הנכונות.

תוצאה נוספת מתייחסת לאוטומציה שביצענו למערכת – הצלחנו להגדיל את קצב איסוף הדאטה מכ10-תמונות לשעה כשאספנו אותן ידנית, לכ400- תמונות בשעה עם המערכת האוטומטית.

## מסקנות

המסקנה הראשונה והחשובה שבהן – תמונות פיזורים של קרן לייזר אכן מכילות מידע שימושי על המיקום המרחבי של הקרן ועל זווית הפגיעה, וניתן ללמוד מתוך תמונת פיזורים את כל 4 דרגות החופש של הקרן. מסקנה זו ממשיכה את המגמה המחקרית שרואה בתמונות פיזורים כלי חשוב ויעיל לפיתוח יישומים הקשורים בקרני לייזר, למחקר המשטחים דרכם הקרן מתפזרת בדגש למבנה שלהם )אפילו ברמה מיקרונית(.

בנוסף, ניתן לראות כי השערוך שלנו הצליח להתבצע על כל אחת מההזזות המרחביות בנפרד, במה שמוכיח את היכולת של המודל להפריד ולהבחין בין הקואורדינטות השונות מבלי שקואורדינטה אחת תשפיע על החיזוי של אחרת.

מסקנה נוספת הינה שאוטומציה של המערכת הייתה קריטית המיוחד ליכולת שלנו לאסוף מספיק דאטה כדי שהמערכת תצליח ללמוד לשערך את המיקום בצורה מיטבית. לפני כן קצב איסוף הדאטה היה איטי מאוד וגם לאחר ימים של איסוף דאטה ידני לא הצלחנו להתקרב להתכנסות של המודל.

מסקנה שלישית היא שמודל מסוג learning supervised הוכיח את עצמו גם בבעיית קליברציה, ושדיסקרטיזציה של המיקום אכן מובילה אותנו לתוצאות מיטביות. החיסרון היחסי בשיטה כזו היא שדיסקרטיזציה מאלצת אותנו לקבוע רזולוציה ספציפית שבה אנו מסוגלים לשערך את המיקום. עם זאת, הצעה שכדאי לבחון בהמשך ועשויה אף ל שפר את הרזולוציה אליה ניתן להגיע ואת ביצועי השיערוך ת היה שילוב של learning supervised עם מודל של learning reinforcement. הסיבה לכך נעוצה בעובדה שכשמתקרבים לנקודת האפס של הקרן, ניתן לראות בבירור את מה שפעם היה מרכז האלומה. לכן קל מאוד לעבוד בשיטת DQN ו להגדיר פונקציית Q – בסה"כ נרצה שהמודל ינסה למרכז את העיגול הבהיר שנוצר מ התפזרות של מרכז האלומה. הבאת העיגול הבהיר למרכז שקולה למעשה לכיול הקרן, מכיוון שזה אומר שמרכז הקרן פוגע בחיישן. הסיבה שבגללה כדאי לשלב גם learning supervised ולא רק DQN היא שלא בכל תמונה ניתן לראות בבירור סימן למרכז האלומה, וכשמתרחקים מהמרכז ניתן לראות רק תבניות של חלקיקי הפיזור. ולכן כדי לנוע בכיוון הנכון עבור נקודות רחוקות אלה כדאי לשלב גם learning supervised כדי להאיץ את תהליך ההתכנסות ולמנוע איטרציות מיותרות. רק כאשר ניתן להבחין בבהירות יחסית שמצביעה על כך שישנו סימן למרכז האלומה בתמונת הפיזור הנוכחית, נרצה להשתמש בלמידה מחיזוקים כדי להגיע לרזולוציות גבוהות במהירות.

מסקנה נוספת נובעת מעצם מהירות ההתכנסות של המודל שלנו – מאחר ועם מאגר דאטה שבאופן יחסי אינו מאוד גדול ביחס לבעיה ונאסף בך הכל ביום אחד הצלחנו באיטרציות בודדות של אימון להגיע לשגיאה כמעט אפסית, הרי שאת הרזולוציה שבחרנו ניתן לשפר מ שמעותית גם מבחינה תיאורטית וגם מהב חינה הטכנית.
אנחנו בחרנו ברזולוציה של סיבוב אחד המנוע, שהיא אמנם גם כך מתבטאת בשינוי מאוד קטן במיקום הלייזר בפועל, אבל המנועים שלנו מסוגלים להגיע לרזולוציות גבוהות בהרבה – מאחר ומנוע הצעד יכול גם
1 | לבצע מיקרו-צעד, אנחנו יכולים להגיע לרזולוציות של עד כדי
12800

סיבוב.

הצעה חשובה להמשך תהיה לבדוק לאיזו רזולוציה אנו מסוגלים להגיע ועדיין לשמור על טווח שגיאה סביר יחסית ולהצליח לאמן מודל מתכנס. זה ככל הנראה יצריך משמעותית יותר דאטה משהספקנו לייצר ולכן מפאת קוצר זמן התפשרנו על רזולוציה יותר ריאלית שהיא עדיין יחסית טובה. אם אכן יצליחו לגלות במחקר מעמיק יותר שניתן להגיע לרזולוציות מאוד גבוהות השימוש של הפרויקט שלנו בתעשיה ובמחקר אכן יוכל להחליף את השיטות הקיימות לקליברציה של קרני לייזר. באפליקציות שדורשות דיוק רב כגון ייצור צ'יפים וחיתוכם, או באמל"ח ומערכות צבאיות, השיטה שלנו שמאפשרת תגובה מהירה יותר מהשיטות הקיימות בשילוב עם רזולוציה גבוהה יכולה להיות משמעותית ופורצת דרך.

## תיעוד

התיעוד לפרוייקט נעשה בעיקרו ב-GitHub . הקישור לריפו: https://github.com/AsherAlmog/Laser_calibration_proj.git
בגיט ניתן למצוא את הסקריפט בארדואינו שבאמצעותו הנענו את מנועי הצעד, את הסקריפט בפייתון שרץ על ה-RPI ששימש לתקשורת בין הראסברי לבין הארדואינו ולצילום התמונות עם הראסברי פאי. כמו כן יש שם את הקוד שבאמצעותו אימנו את הרשת וכן את פרמטרי המודל המאומן. כבונוס ניתן למצוא שם גם את מודלי התלת מימד ששימשו להתממשקות הסטאפ למנועים, במידה ויהיה מי שירצה לשחזר את מה שעשינו בעתיד ולהעמיק את המחקר בנושא. פירוט יינתן ב קובץ ה-README שנמצא גם הוא בגיט.

## ביבליוגרפיה

i Laser speckle photometry – Optical sensor systems for condition and process monitoring:
Lili Chen, Ulana Cikalova, Beatrice Bendjus, Andreas Gommlich, Shohag Roy Sudip, Carolin Schott, Juliane Steingroewer, Dresden, Matthias Belting, Aachen, and Stefan Kleszczynski, Duisburg, Germany
ii https://www.rp-photonics.com/laser_speckle.html - laser speckles, speckle images
iii https://www.sitechwest.com/content/uploads/2016/01/hv101-calibrationcheck.pdf - laser calibration method
iv https://opg.optica.org/oe/fulltext.cfm?uri=oe-28-19-27588&id=437846 – laser calibration using interpolation
v https://www.raspberrypi.com/products/raspberry-pi-4-model-b/ - Raspberry-pi 4 product page vi https://www.raspberrypi.com/documentation/accessories/camera.html#installing-a-raspberry-pi-camera (https://www.raspberrypi.com/documentation/accessories/camera.html#installing-a-raspberry-pi-camera) – CSI camera connector
vii https://datasheets.raspberrypi.com/rpi4/raspberry-pi-4-reduced-schematics.pdf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 4NTk1Njk5MS4xLjEuMTY4NTk1NzE3OS4wLjAuMA. (https://datasheets.raspberrypi.com/rpi4/raspberry-pi-4-reduced-schematics.pdf) – Raspberry pi full schematic
viii https://store.arduino.cc/products/arduino-mega-2560-rev3 –Ardunio mega
ix https://reprap.org/wiki/RAMPS_1.4 – RAMPS 1.4
x https://reprap.org/wiki/File:Rampswire14.svg - Appropriate connections between Arduino, RAMPS 1.4 and stepper motors
xi https://reprap.org/wiki/MKS_DRV8825\ - DRV8825
xii https://en.wikipedia.org/wiki/H-bridge - H-Bridge
xiii
https://html.alldatasheet.com/html-pdf/28616/TI/SN754410NE/169/6/SN754410NE.html -SN754410NE datasheet

xiv https://towardsdatascience.com/optimization-algorithms-in-deep-learning-191bfc2737a4 - ADAM optimizer theoretical background

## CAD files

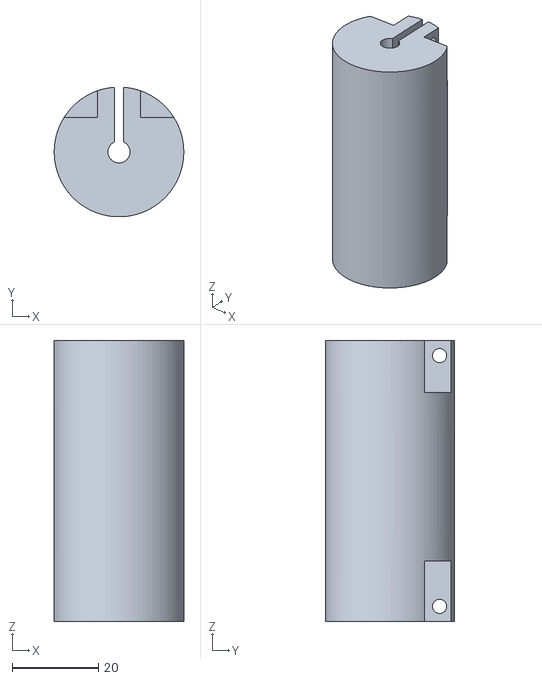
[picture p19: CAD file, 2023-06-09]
3D_models_STL_files/coupler_13.stl
30.0 x 30.0 x 65.0

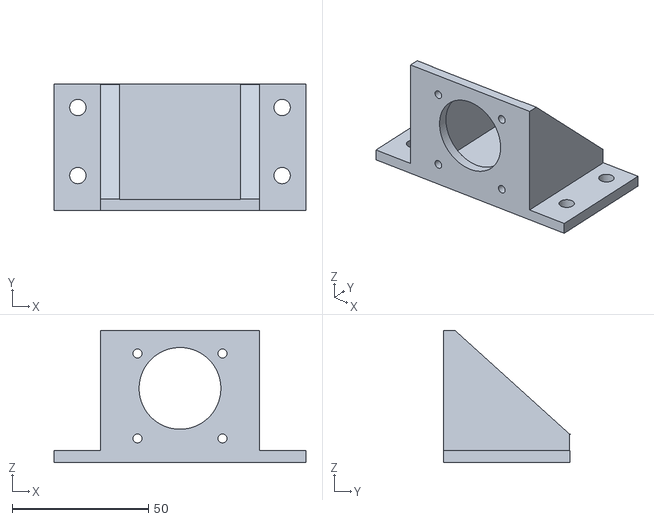
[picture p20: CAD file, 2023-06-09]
3D_models_STL_files/stepper_holder_z.stl
92.5 x 46.5 x 48.5

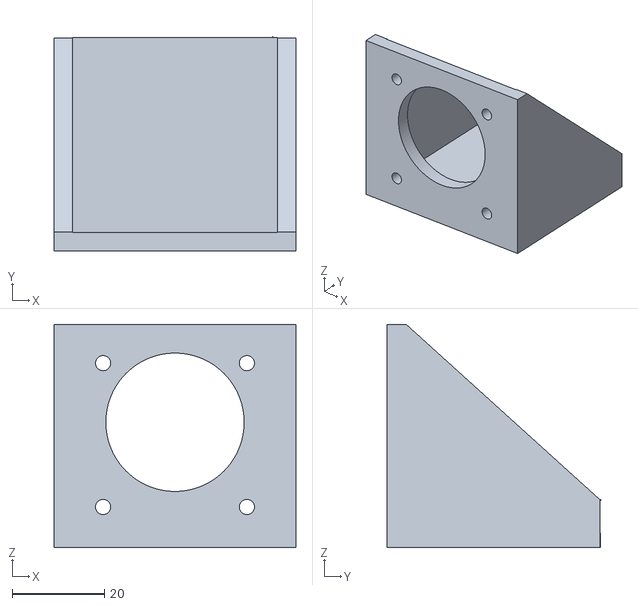
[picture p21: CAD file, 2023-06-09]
3D_models_STL_files/narrowed stepper holder.stl
52.5 x 46.5 x 48.5

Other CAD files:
3D_models_STL_files/coupler_13mm v2.stl

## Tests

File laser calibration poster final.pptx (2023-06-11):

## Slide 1

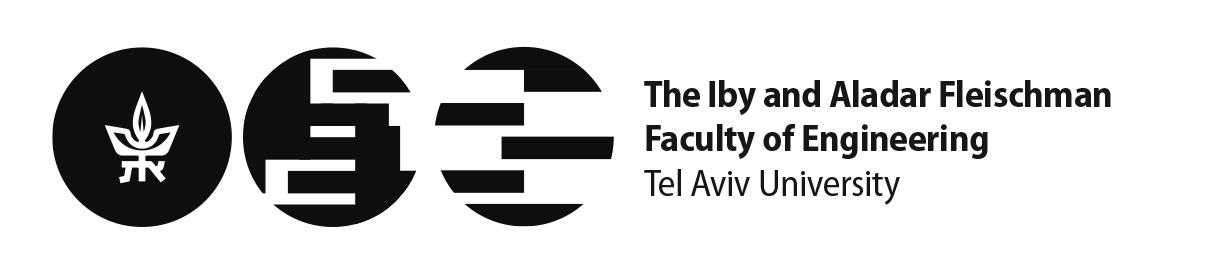
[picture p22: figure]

Laser Calibration
Project Number: 22-1-1-2456
Names: Almog Asher and Bar Zahavi
Advisor:Khen Cohen, Co-Advisor: Ofer Kfir

Introduction Our project is meant to be a breakthrough in the area of Laser Calibration – it suggests the possibility of calibrating a laser beam using only a single camera. The problem is as follows – laser calibration requires knowing precisely 4 coordinates of the beam – its X, Y location, and the angles for both axis. Nowadays if one wishes to calibrate a laser beam, it requires two High-resolution cameras – one for the angles and one for the X,Y location. Our project was meant to utilize two relatively new areas of research in order to reduce the number of cameras to one and simplify th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 | Methods and implementation The physical setup Figure 2: the optical system: The physical setup is made of manual stages that were found in the lab and remained unused. We used stepper motors to convert the stages to autonomous ones, and 3D printing to create couplers and stands that would connect the motors to the stages. An Arduino is used to drive the motors, and a raspberry-pi 4 is used to take the speckle images. Data collection In order to collect a huge amount of data quickly and efficiently, we used serial communication between the Arduino and Raspberry-pi. Figure 3: raspberry-pi and 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 | Observed automation benefits The automation of the system allowed us to collect about 450 images/hour, after being able to collect only 10 images/hour manually. We collected our dataset of 4400 images of hundreds of different coordinates in only one day. Deep learning network For the deep learning network, we used pyTorch’s resNet-18. We split our data to an 80% train data and 20% test data. We used an Adam optimizer and MSE loss as our criteria. Results Figure 4: an MSE loss graph for our train test data: We can observe that the MSE loss converges to zero for both the training samples and m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

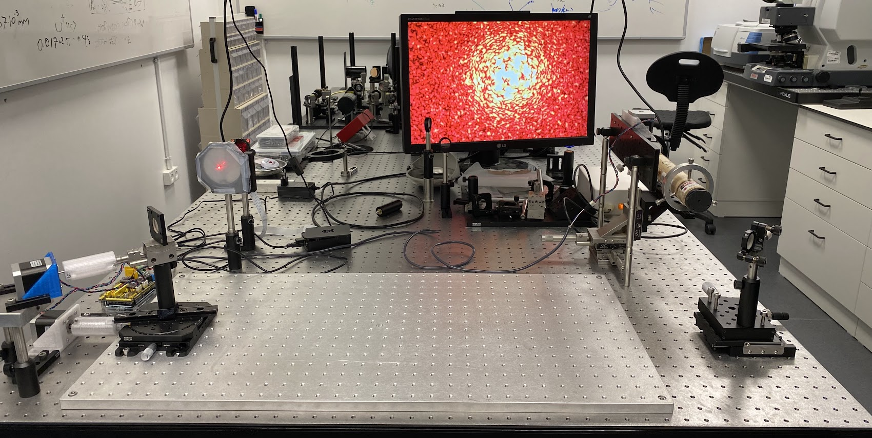
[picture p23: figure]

Arduino

The speckles image

Mirror 2

camera

Dispersion field

laser

Raspberry pi

Stepper motors

Mirror 1

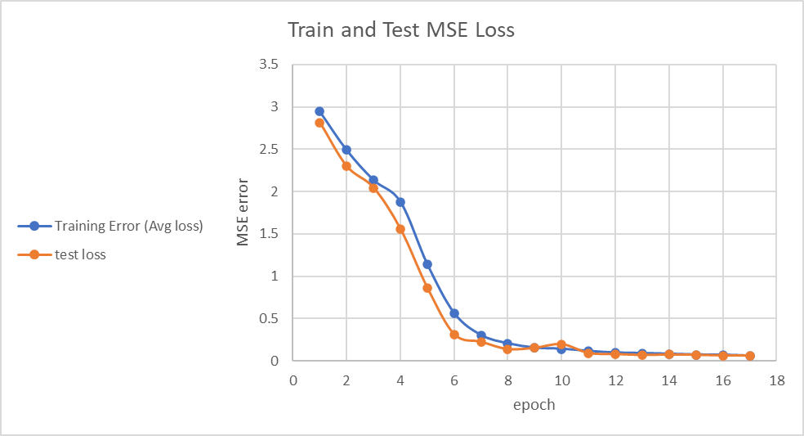
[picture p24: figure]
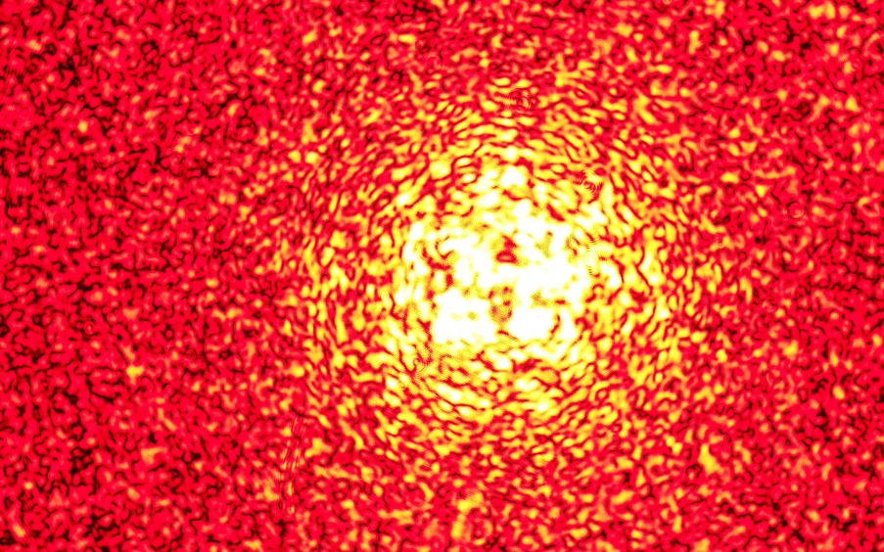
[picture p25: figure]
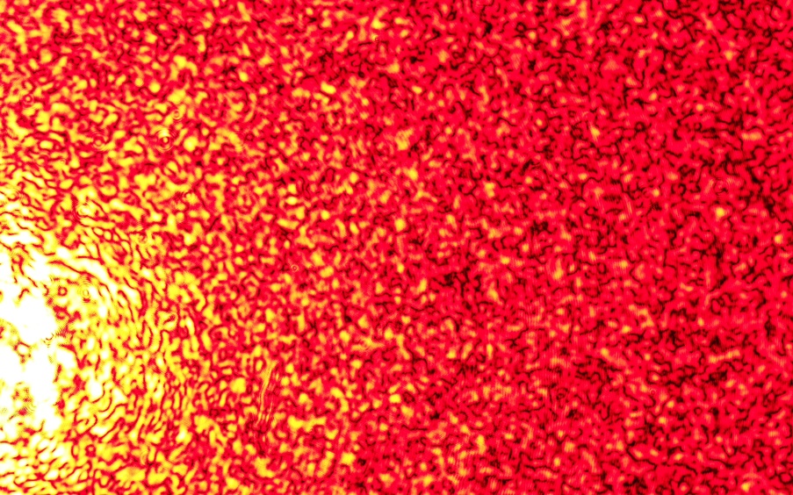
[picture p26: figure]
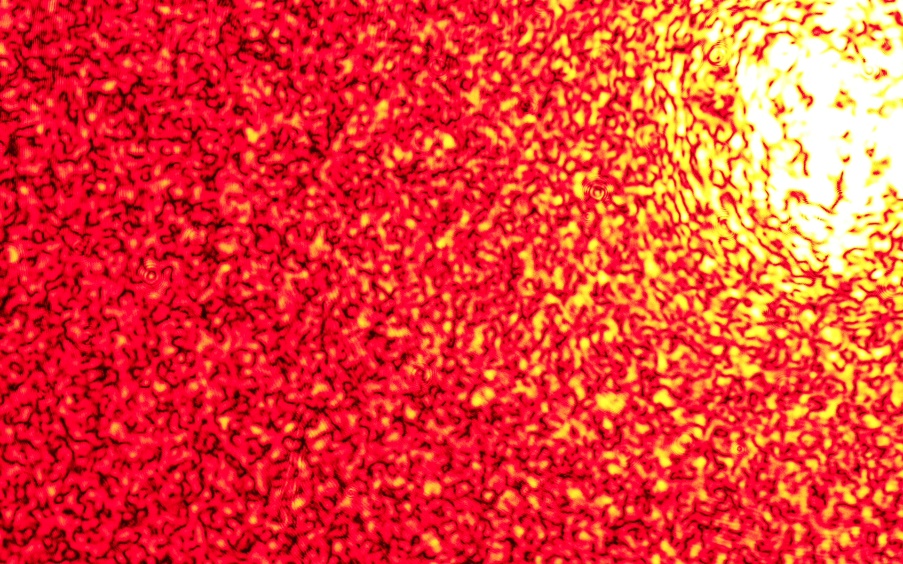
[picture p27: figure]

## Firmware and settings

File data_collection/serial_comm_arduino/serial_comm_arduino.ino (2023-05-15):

#include <ArduinoJson.h>
#include <SoftwareSerial.h>

// we should connect z stepper to X PIN, x stepper to E1 and theta to E2

// Define the stepper motor connections
#define X_STEP_PIN         54
#define X_DIR_PIN          55
#define X_ENABLE_PIN       38
#define Y_STEP_PIN         60
#define Y_DIR_PIN          61
#define Y_ENABLE_PIN       56
#define Z_STEP_PIN         46
#define Z_DIR_PIN          48
#define Z_ENABLE_PIN       62
#define E1_STEP_PIN        26
#define E1_DIR_PIN         28
#define E1_ENABLE_PIN      24
#define E2_STEP_PIN        36
#define E2_DIR_PIN         34
#define E2_ENABLE_PIN      30

#define MICRO_STEPS      32

// Define the number of steps per revolution for the stepper motors
#define STEPS_PER_REV     12800

// Define the number of rotations to perform
#define NUM_ROTATIONS      20

// Define the speed at which the motors should rotate (in steps per second)
#define SPEED              1*400*32

int32_t speedStep = 2*10^6/STEPS_PER_REV/2; // Speed/sec = second * num microseconds / num steps per revolution / delay twice
//SoftwareSerial mySerial(2, 3); // RX, TX


String inputString = "";         // a String to hold incoming data
bool stringComplete = false;  // whether the string is complete

void setup() {
  Serial.begin(9600);
  while (!Serial) continue; // Wait for serial connection
  // reserve 200 bytes for the inputString:
  inputString.reserve(200);
  // Set the enable pins for each motor                                                                                                                                                                                         
  pinMode(X_ENABLE_PIN, OUTPUT);
  digitalWrite(X_ENABLE_PIN, LOW);
  pinMode(Y_ENABLE_PIN, OUTPUT);
  digitalWrite(Y_ENABLE_PIN, LOW);
  pinMode(Z_ENABLE_PIN, OUTPUT);
  digitalWrite(Z_ENABLE_PIN, LOW);
  pinMode(E1_ENABLE_PIN, OUTPUT);
  digitalWrite(E1_ENABLE_PIN, LOW);
  pinMode(E2_ENABLE_PIN, OUTPUT);
  digitalWrite(E2_ENABLE_PIN, LOW);

  pinMode(Z_STEP_PIN, OUTPUT);
  digitalWrite(Z_STEP_PIN, LOW);

  pinMode(Z_DIR_PIN, OUTPUT);
  digitalWrite(Z_DIR_PIN, LOW);

  pinMode(E1_STEP_PIN, OUTPUT);
  digitalWrite(E1_STEP_PIN, LOW);

  pinMode(E1_DIR_PIN, OUTPUT);
  digitalWrite(E1_DIR_PIN, LOW);

    pinMode(E2_STEP_PIN, OUTPUT);
  digitalWrite(E2_STEP_PIN, LOW);

  pinMode(E2_DIR_PIN, OUTPUT);
  digitalWrite(E2_DIR_PIN, LOW);

}
int flag = 1;
int x = 0;
int theta = 0;
int z = 0;
int dirz = 0;
int dirx = 0;
int dirtz = 0;
void loop() {
  digitalWrite(X_DIR_PIN, LOW);
  digitalWrite(E1_DIR_PIN, LOW);
  digitalWrite(E2_DIR_PIN, LOW);
// *** if there's an isuue try initializing the pins to LOW here *** 
  if (Serial&&flag){
      Serial.println("ready"); 
      flag = 0;   
  }
  // Parse incoming string
  if (stringComplete) {
    StaticJsonDocument<250> incoming_doc;
    DeserializationError error = deserializeJson(incoming_doc, inputString);
    if (!error) {
      // Process incoming coordinates json file
      if (incoming_doc.containsKey("z")&& incoming_doc.containsKey("x")&& incoming_doc.containsKey("theta")&& incoming_doc.containsKey("dirz")&& incoming_doc.containsKey("dirx")&&incoming_doc.containsKey("dirtz")) {
        z = incoming_doc["z"].as<int>();
        theta = incoming_doc["theta"].as<int>();
        x = incoming_doc["x"].as<int>();
        dirz = incoming_doc["dirz"].as<int>();
        dirtz = incoming_doc["dirtz"].as<int>();
        dirx = incoming_doc["dirx"].as<int>();
        // choose which direction to spin based on the json input
        if(dirx==0){
          digitalWrite(E1_DIR_PIN, LOW);        
        }
        else{
          digitalWrite(E1_DIR_PIN, HIGH);
        }
        if(dirtz==0){
          digitalWrite(E2_DIR_PIN, LOW);          
        }
        else{
          digitalWrite(E2_DIR_PIN, HIGH);
        }
        if(dirz==0){
          digitalWrite(X_DIR_PIN, LOW);         
        }
        else{
          digitalWrite(X_DIR_PIN, HIGH);
        }
        //make rotations based on the json file input
        for (int k=0; k<z; k++){
          for (int i = 0; i<STEPS_PER_REV; i++){
            digitalWrite(X_STEP_PIN, LOW);
            delayMicroseconds(speedStep);
            digitalWrite(X_STEP_PIN, HIGH);
            delayMicroseconds(speedStep);
          }
          delay(300); // wait 0.3 sec between each spin
        }
        for (int k=0; k<x; k++){
          for (int i = 0; i<STEPS_PER_REV; i++){
            digitalWrite(E1_STEP_PIN, LOW);
            delayMicroseconds(speedStep);
            digitalWrite(E1_STEP_PIN, HIGH);
            delayMicroseconds(speedStep);
          }
          delay(300); // wait 0.3 sec between each spin
        }
        for (int k=0; k<theta; k++){
          for (int i = 0; i<STEPS_PER_REV; i++){
            digitalWrite(E2_STEP_PIN, LOW);
            delayMicroseconds(speedStep);
            digitalWrite(E2_STEP_PIN, HIGH);
            delayMicroseconds(speedStep);
          }
          delay(300); // wait 0.3 sec between each spin
        }
        delay(500); // wait 0.5 sec after finishing each movement
        // now tell the RPI that rotating is over
        Serial.println("moved");
      }
    }
    inputString = ""; // empty the input string to be able to recieve a new one
    stringComplete = false;
  }
  
}

void serialEvent() {
  while (Serial.available()) {
    // get the new byte:
    char inChar = (char)Serial.read();
    // add it to the inputString:
    inputString += inChar;
    // if the incoming character is a newline, set a flag so the main loop can
    // do something about it:
    if (inChar == '\n') {
      stringComplete = true;
    }
  }
}

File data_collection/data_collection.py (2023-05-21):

import serial
import threading
import json
import time
import matplotlib.pyplot as plt
import matplotlib.animation as animation
from collections import deque
import picamera
import os

def capture_pic(x,z,theta,preview_flag, root_dir):
    with picamera.PiCamera() as camera:
        # camera.resolution = resolution
        if(preview_flag):
            camera.start_preview()
        time.sleep(1)  # wait for the camera to warm up
        img_name = os.path.join(root_dir, f"{x},{z},{theta}.jpg")
        camera.capture(img_name)
        if (preview_flag):
            camera.stop_preview()
        print(f"Captured image {x},{z},{theta}: {img_name}")


def flip_dir(dir):
    if (dir==1):
        return 0
    if(dir == 0):
        return 1

def decide_dir(num):
    if num < 0:
        return 1
    else:
        return 0


baud_rate = 9600
port = 'COM5'
ser = serial.Serial(port, baud_rate)  # , timeout=10)
# Clear the input and output buffers of the serial port
ser.flushInput()
ser.flushOutput()
print("starting the comm")
coordinates_dict = {'x': 0, 'z': 0, 'theta': 0, 'dirz': 0, 'dirx':1, 'dirtz':0}
pic_dict = {'pic': 'taken'}
ack_msg = ""
ack_msg = ser.readline().decode().strip()
while ack_msg != "ready":
    ack_msg = ser.readline().decode().strip()
print(f"ack_msg is {ack_msg}")
ack_msg = ""
# the vectors are organized in this order: [x,z,theta_z]
bottom_bound = [8, 6, 1]
upper_bound = [9, 7, 2]
range_arr = [1, 1, 1]

root_dir = "C:/Users/asher/PycharmProjects/Laser_calibration_proj/speckles_pic"
start_iter = 0
num_iterations = 15
first_run_flag = 1
for z in range(bottom_bound[1], upper_bound[1] + 1, range_arr[1]):
    first_run_flag = first_run_flag - 1
    for iter in range(num_iterations):
        for x in range(bottom_bound[0], upper_bound[0]+1, range_arr[0]):
            for theta in range(bottom_bound[2], upper_bound[2] + 1, range_arr[2]):
                if first_run_flag >= 0:  # if that's the first run spin z motor to the desired position
                    send_z = z
                else:  # else spin it only by the needed range
                    send_z = range_arr[1]

                coordinates_dict['z'] = abs(send_z)
                coordinates_dict['x'] = abs(x)
                coordinates_dict['theta'] = abs(theta)
                coordinates_dict['dirz'] = decide_dir(send_z)
                coordinates_dict['dirx'] = decide_dir(x)
                coordinates_dict['dirtz'] = decide_dir(theta)

                json_str = json.dumps(coordinates_dict)+'\n'
                json_str = json_str.encode('utf-8')
                ser.write(json_str)
                print(f"Sent json {coordinates_dict} to arduino")

                # wait for a message from arduino that he moved to position
                ack_msg = ser.readline().decode().strip()
                while ack_msg != "moved":
                    ack_msg = ser.readline().decode().strip()
                print(f"ack_msg is {ack_msg}")
                ack_msg = ""
                # now we should take a pic
                capture_pic(x, z, theta, 0, root_dir)
                coordinates_dict['z'] = 0
                # now tell the arduino to turn the other way by flipping dir
                curr_dir_z = coordinates_dict['dirz']
                curr_dir_x = coordinates_dict['dirx']
                curr_dir_tz = coordinates_dict['dirtz']

                coordinates_dict['dirz'] = flip_dir(curr_dir_z)
                coordinates_dict['dirx'] = flip_dir(curr_dir_x)
                coordinates_dict['dirtz'] = flip_dir(curr_dir_tz)

                json_str = json.dumps(coordinates_dict) + '\n'
                json_str = json_str.encode('utf-8')
                ser.write(json_str)
                print(f"Sent json {coordinates_dict} flipped to arduino")

                ack_msg = ser.readline().decode().strip()
                while ack_msg != "moved":
                    ack_msg = ser.readline().decode().strip()
                print(f"ack_msg after flipping is {ack_msg}")
                ack_msg = ""

                # now flip back the direction

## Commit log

2023-05-21 modified data collection so that z motor only moves once
2023-06-09 reordered files
    [coupler_13.stl, coupler_13mm v2.stl, narrowed stepper holder.stl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]
